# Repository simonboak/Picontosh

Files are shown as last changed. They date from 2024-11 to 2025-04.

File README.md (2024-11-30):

# Picontosh: The Pi-Icon-Macintosh...

Exploring original Macintosh icon resources and turning them into a small desktop display.

[Read the blog post here](https://unimplementedtrap.com/picontosh-exploring-classic-macintosh-icon-format)

Files for the 3D printed case can be found in the STL folder. It's designed around the Waveshare Pico ResTouch LCD.

## Video

https://github.com/user-attachments/assets/4b654132-9139-4be3-bfa3-c3547d9ef671

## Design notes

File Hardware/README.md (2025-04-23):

# Building a Picontosh

This folder contains the STL and STEP files needed to print the case. I printed the front face-down and the rear placed on its back. Both were printed with supports. 

You'll need 2 copies of the screen bracket: these attach to the back of the LCD using the hex standoffs that come with the display before you screw it into the case.

## Parts list

The components should all be available from various suppliers:

- Waveshare "PICO-RESTOUCH-LCD-2.8" https://www.waveshare.com/wiki/Pico-ResTouch-LCD-2.8 
- SD card extender, mine came with sticky double-sided pad to attach it to the inside of the case https://www.amazon.co.uk/POFET-Adapter-extension-Multiple-Printers/dp/B0C4L7DDZF/
- Panel mount right angle USB cable (will need to be USB Micro or USB-C depending on model of Pico) https://www.amazon.co.uk/Extension-Adapter-Charging-Raspberry-Printers/dp/B08XVTVMVS/
- M3 self tapping screws: 5x 8mm long, 1x 30 mm long

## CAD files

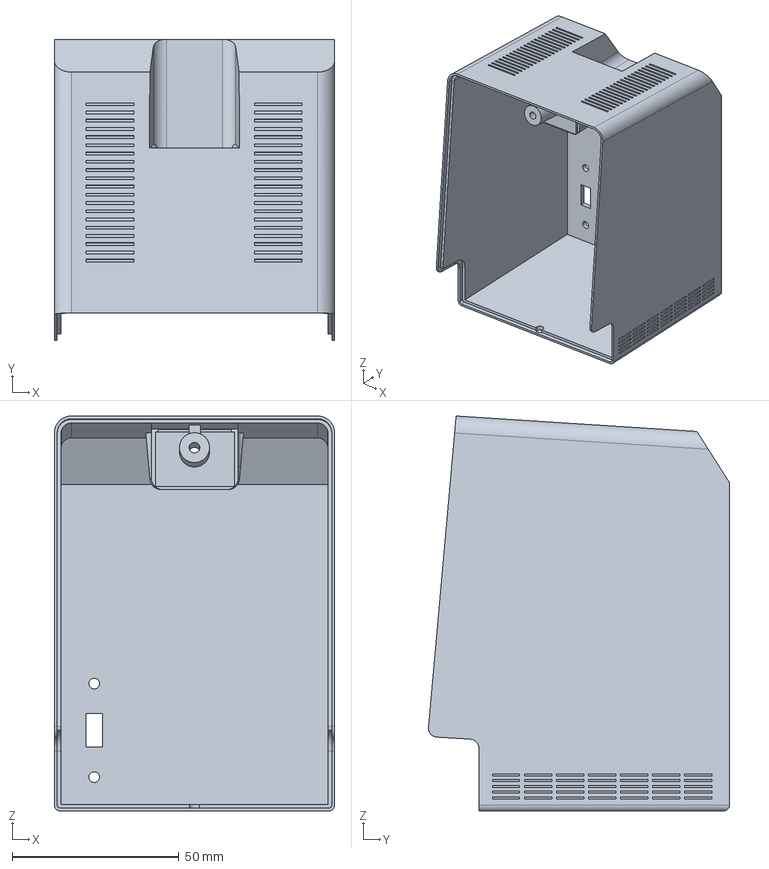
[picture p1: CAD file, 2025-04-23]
Hardware/Picontosh - Case Back.stp
84.0 x 90.2 x 118.3 mm

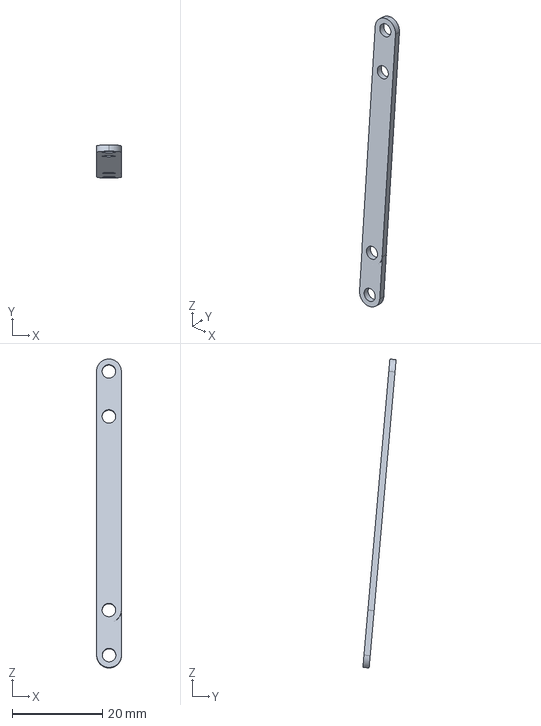
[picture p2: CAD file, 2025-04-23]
Hardware/Picontosh - Screen Bracket.stp
5.54 x 7.36 x 68.4 mm

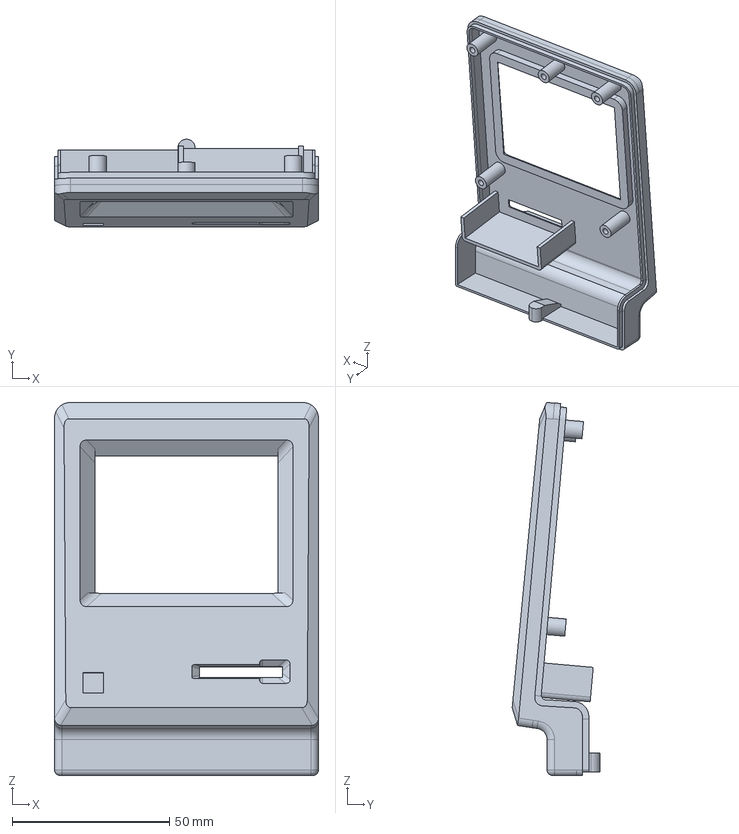
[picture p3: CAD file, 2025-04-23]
Hardware/Picontosh - Case Front.stp
84.0 x 27.9 x 118.6 mm

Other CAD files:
Hardware/Picontosh - Case Back.stl
Hardware/Picontosh - Case Front.stl
Hardware/Picontosh - Screen Bracket.stl

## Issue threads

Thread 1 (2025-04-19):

Pi Zero 2 W

seeharrison, 2025-04-19:
Not really and issue, but more of a question. I'm totally new to the RPi world and Python. What would it take to run this on a Pi Zero 2 W that has a small display connected via HDMI? I'd love to run in on my miniature original Macintosh. Great work and awesome project!

Cheers!

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

simonboak, 2025-04-21:
That's a cute printed Mac!

Yes what you're asking is possible, however would be making quite a lot of changes across the project.

You'd want to base this on something like Pygame or another SDL library to handle the graphics. This replaces the "SSD" calls which are specific to the display controller I used. I think there's also a few places where the screen resolution was hardcoded so would need changing too.

The SD card library can be removed as you'll just be able to access the filesystem directly to load the icons.

Is this a project you're interested in tackling? Feel free to fork this if you wish.

seeharrison, 2025-04-21:
Thanks for the quick reply!

It sounds like I may just want to invest in a new display and use a Pico I already have. lol

Do you have a materials list for this project?

Cheers

seeharrison, 2025-04-29:
Thanks! Just got the display and a new Pico. Now to figure out how to make it all work. lol Thanks for putting this project up.

simonboak, 2025-04-29:
Thanks for the keen interest! BTW, if you'd rather I've got other contact methods at the very bottom of my website: https://unimplementedtrap.com

Always happy to hear about people's projects

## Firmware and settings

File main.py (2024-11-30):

"""
  Picontosh: The Pi-Icon-Macintosh....

  Exploring original Macintosh icon resources and turning them into a small desktop display.

  Released under the MIT License (MIT).
  Copyright (c) 2024 Simon Boak, Unimplemented Trap
  http://unimplementedtrap.com/

"""

import time
import gc
from machine import Pin, SPI
from uctypes import bytearray_at, addressof
from st7789 import *
import sdcard
import os
import random
import ChicagoSB_12
import slowdraw
import slowtype

def icon_to_framebuffer(iconData):
  buf = framebuf.FrameBuffer(bytearray(32 * 32 * 2), 32, 32, framebuf.RGB565)
  bytesInLine = 0
  y = 0
  x = 0
  for i in range(len(iconData)):
    pixelByte = iconData[i]

    bitNumber = int(128)
    while bitNumber > 0:
      if pixelByte&bitNumber != 0:
        buf.pixel(x, y, BLACK)

      x = x + 1
      bitNumber = int(bitNumber / 2)

    bytesInLine = bytesInLine + 1
    if bytesInLine == 4:
      y = y + 1
      x = 0
      bytesInLine = 0
  return buf

def draw_boot_screen(slowtyper):
  time.sleep_ms(300)
  # Draw the boot message box
  ssd.fill_rect(50, 30, 220, 75, WHITE)
  ssd.rect(50, 30, 220, 75, BLACK)

  strBuffer, width = slowtyper.buffer_from_str('Starting up...')
  ssd.blit(strBuffer, int((320 - width) / 2), 52)

  ssd.show()

def load_icons(all_icons):
  sd = sdcard.SDCard(spi, Pin(22, Pin.OUT), 10_000_000)
  os.mount(sd, '/sd', readonly=True)

  icnsFileMagicNumber = b'\x69\x63\x6E\x73'
  ICNrsrcMagicNumber  = b'\x49\x43\x4E\x23'

  file_list = os.listdir('/sd')
  print('Loading ICN files')
  for i in range(len(file_list)):
    gc.collect()
    print('Mem free: ' + str(gc.mem_free()))
    slowdraw.draw_progress_bar(ssd, 110, 78, i, len(file_list) - 1)

    if file_list[i][:1] == '.':
      continue
    try:
      with open('/sd/' + file_list[i], 'rb') as f:
        s = f.read()
        if s.find(icnsFileMagicNumber) == 0:
          iconResourcePosition = s.find(ICNrsrcMagicNumber)
          if iconResourcePosition > 0:
            all_icons.append((file_list[i].replace('.icns', ''), s[iconResourcePosition + 8:iconResourcePosition + 8 + 128]))
    except:
      print('Error: Skipping "' + file_list[i] + '"')
      continue

  os.umount("/sd")


if __name__ == "__main__":
  SSD = ST7789

  pdc = Pin(8, Pin.OUT, value=0)
  pcs = Pin(9, Pin.OUT, value=1)
  prst = Pin(15, Pin.OUT, value=1)
  pbl = Pin(13, Pin.OUT, value=1)

  gc.collect()  # Precaution before instantiating framebuf
  # Max baudrate produced by Pico is 31_250_000. ST7789 datasheet allows <= 62.5MHz.
  # Note non-standard MISO pin. This works, verified by SD card.
  spi = SPI(1, 60_000_000, sck=Pin(10), mosi=Pin(11), miso=Pin(12))

  # Define the display
  # For landscape mode:
  ssd = SSD(spi, height=240, width=320, disp_mode=4, dc=pdc, cs=pcs, rst=prst)
  ssd.fill(ssd.rgb(0xFF,0xFF,0xFF))
  ssd.show()

  slowtyper = slowtype.Slowtype(ChicagoSB_12, framebuf.RGB565)

  BLACK = ssd.rgb(0x00,0x00,0x00)
  WHITE = ssd.rgb(0xFF,0xFF,0xFF)


  slowdraw.clear_screen_with_grey(ssd)
  draw_boot_screen(slowtyper)

  all_icons = []
  load_icons(all_icons)

  slowdraw.clear_screen_with_grey(ssd)
  slowdraw.draw_menu_bar(ssd, slowtyper, ['File', 'Edit', 'View', 'Label', 'Special'])

  windowWidth = 148
  windowHeight = 120

  while True:
    windowX = random.randint(5, 320 - windowWidth - 5)
    windowY = random.randint(20, 240 - windowHeight)

    icon_index = random.randint(0, len(all_icons) - 1)
    random_icon_buffer = icon_to_framebuffer(all_icons[icon_index][1])
    windowTitleWidth = slowdraw.draw_window(ssd, slowtyper, windowX, windowY, windowWidth, windowHeight, all_icons[icon_index][0])

    iconX = int((windowWidth - 32) / 2) + windowX
    iconY = int((windowHeight - 32 - 18) / 2) + windowY + 9
    ssd.blit(random_icon_buffer, iconX, iconY)

    ssd.show()

    gc.collect()

    time.sleep_ms(2000)

    slowdraw.deactivate_window(ssd, windowX, windowY, windowWidth, windowTitleWidth)

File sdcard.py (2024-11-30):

"""
Taken from: https://github.com/micropython/micropython-lib/blob/master/micropython/drivers/storage/sdcard/sdcard.py
https://github.com/micropython/micropython-lib/tree/master?tab=License-1-ov-file#readme

MicroPython driver for SD cards using SPI bus.

Requires an SPI bus and a CS pin.  Provides readblocks and writeblocks
methods so the device can be mounted as a filesystem.

Example usage on pyboard:

    import pyb, sdcard, os
    sd = sdcard.SDCard(pyb.SPI(1), pyb.Pin.board.X5)
    pyb.mount(sd, '/sd2')
    os.listdir('/')

Example usage on ESP8266:

    import machine, sdcard, os
    sd = sdcard.SDCard(machine.SPI(1), machine.Pin(15))
    os.mount(sd, '/sd')
    os.listdir('/')

"""

from micropython import const
import time


_CMD_TIMEOUT = const(100)

_R1_IDLE_STATE = const(1 << 0)
# R1_ERASE_RESET = const(1 << 1)
_R1_ILLEGAL_COMMAND = const(1 << 2)
# R1_COM_CRC_ERROR = const(1 << 3)
# R1_ERASE_SEQUENCE_ERROR = const(1 << 4)
# R1_ADDRESS_ERROR = const(1 << 5)
# R1_PARAMETER_ERROR = const(1 << 6)
_TOKEN_CMD25 = const(0xFC)
_TOKEN_STOP_TRAN = const(0xFD)
_TOKEN_DATA = const(0xFE)


class SDCard:
    def __init__(self, spi, cs, baudrate=1320000):
        self.spi = spi
        self.cs = cs

        self.cmdbuf = bytearray(6)
        self.dummybuf = bytearray(512)
        self.tokenbuf = bytearray(1)
        for i in range(512):
            self.dummybuf[i] = 0xFF
        self.dummybuf_memoryview = memoryview(self.dummybuf)

        # initialise the card
        self.init_card(baudrate)

    def init_spi(self, baudrate):
        try:
            master = self.spi.MASTER
        except AttributeError:
            # on ESP8266
            self.spi.init(baudrate=baudrate, phase=0, polarity=0)
        else:
            # on pyboard
            self.spi.init(master, baudrate=baudrate, phase=0, polarity=0)

    def init_card(self, baudrate):
        # init CS pin
        self.cs.init(self.cs.OUT, value=1)

        # init SPI bus; use low data rate for initialisation
        self.init_spi(100000)

        # clock card at least 100 cycles with cs high
        for i in range(16):
            self.spi.write(b"\xff")

        # CMD0: init card; should return _R1_IDLE_STATE (allow 5 attempts)
        for _ in range(5):
            if self.cmd(0, 0, 0x95) == _R1_IDLE_STATE:
                break
        else:
            raise OSError("no SD card")

        # CMD8: determine card version
        r = self.cmd(8, 0x01AA, 0x87, 4)
        if r == _R1_IDLE_STATE:
            self.init_card_v2()
        elif r == (_R1_IDLE_STATE | _R1_ILLEGAL_COMMAND):
            self.init_card_v1()
        else:
            raise OSError("couldn't determine SD card version")

        # get the number of sectors
        # CMD9: response R2 (R1 byte + 16-byte block read)
        if self.cmd(9, 0, 0, 0, False) != 0:
            raise OSError("no response from SD card")
        csd = bytearray(16)
        self.readinto(csd)
        if csd[0] & 0xC0 == 0x40:  # CSD version 2.0
            self.sectors = ((csd[8] << 8 | csd[9]) + 1) * 1024
        elif csd[0] & 0xC0 == 0x00:  # CSD version 1.0 (old, <=2GB)
            c_size = (csd[6] & 0b11) << 10 | csd[7] << 2 | csd[8] >> 6
            c_size_mult = (csd[9] & 0b11) << 1 | csd[10] >> 7
            read_bl_len = csd[5] & 0b1111
            capacity = (c_size + 1) * (2 ** (c_size_mult + 2)) * (2**read_bl_len)
            self.sectors = capacity // 512
        else:
            raise OSError("SD card CSD format not supported")
        # print('sectors', self.sectors)

        # CMD16: set block length to 512 bytes
        if self.cmd(16, 512, 0) != 0:
            raise OSError("can't set 512 block size")

        # set to high data rate now that it's initialised
        self.init_spi(baudrate)

    def init_card_v1(self):
        for i in range(_CMD_TIMEOUT):
            time.sleep_ms(50)
            self.cmd(55, 0, 0)
            if self.cmd(41, 0, 0) == 0:
                # SDSC card, uses byte addressing in read/write/erase commands
                self.cdv = 512
                # print("[SDCard] v1 card")
                return
        raise OSError("timeout waiting for v1 card")

    def init_card_v2(self):
        for i in range(_CMD_TIMEOUT):
            time.sleep_ms(50)
            self.cmd(58, 0, 0, 4)
            self.cmd(55, 0, 0)
            if self.cmd(41, 0x40000000, 0) == 0:
                self.cmd(58, 0, 0, -4)  # 4-byte response, negative means keep the first byte
                ocr = self.tokenbuf[0]  # get first byte of response, which is OCR
                if not ocr & 0x40:
                    # SDSC card, uses byte addressing in read/write/erase commands
                    self.cdv = 512
                else:
                    # SDHC/SDXC card, uses block addressing in read/write/erase commands
                    self.cdv = 1
                # print("[SDCard] v2 card")
                return
        raise OSError("timeout waiting for v2 card")

    def cmd(self, cmd, arg, crc, final=0, release=True, skip1=False):
        self.cs(0)

        # create and send the command
        buf = self.cmdbuf
        buf[0] = 0x40 | cmd
        buf[1] = arg >> 24
        buf[2] = arg >> 16
        buf[3] = arg >> 8
        buf[4] = arg
        buf[5] = crc
        self.spi.write(buf)

        if skip1:
            self.spi.readinto(self.tokenbuf, 0xFF)

        # wait for the response (response[7] == 0)
        for i in range(_CMD_TIMEOUT):
            self.spi.readinto(self.tokenbuf, 0xFF)
            response = self.tokenbuf[0]
            if not (response & 0x80):
                # this could be a big-endian integer that we are getting here
                # if final<0 then store the first byte to tokenbuf and discard the rest
                if final < 0:
                    self.spi.readinto(self.tokenbuf, 0xFF)
                    final = -1 - final
                for j in range(final):
                    self.spi.write(b"\xff")
                if release:
                    self.cs(1)
                    self.spi.write(b"\xff")
                return response

        # timeout
        self.cs(1)
        self.spi.write(b"\xff")
        return -1

    def readinto(self, buf):
        self.cs(0)

        # read until start byte (0xff)
        for i in range(_CMD_TIMEOUT):
            self.spi.readinto(self.tokenbuf, 0xFF)
            if self.tokenbuf[0] == _TOKEN_DATA:
                break
            time.sleep_ms(1)
        else:
            self.cs(1)
            raise OSError("timeout waiting for response")

        # read data
        mv = self.dummybuf_memoryview
        if len(buf) != len(mv):
            mv = mv[: len(buf)]
        self.spi.write_readinto(mv, buf)

        # read checksum
        self.spi.write(b"\xff")
        self.spi.write(b"\xff")

        self.cs(1)
        self.spi.write(b"\xff")

    def write(self, token, buf):
        self.cs(0)
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

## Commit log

2024-11-30 Adding STLs
    [PicoMac - Case Back Rev0.stl, PicoMac - Case Front Rev0.stl, PicoMac - Screen Bracket Rev0.stl]
2025-04-23 Updating build files
    [Picontosh - Case Back.stl, Picontosh - Case Back.stp, Picontosh - Case Front.stl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]
